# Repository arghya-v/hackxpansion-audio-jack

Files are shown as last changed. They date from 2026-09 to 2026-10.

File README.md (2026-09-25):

# Hackxpansion Audio Jack
This project adds stereo audio playback through a **TLV320DAC3100** DAC and a **3.5 mm headphone jack**, along with physical controls for playback.
<br/>
**Crates**: pkg:cargo/audio_jack_firmware@0.1.0
## Images
the case
pcb
3d

## Schematic
final schematic

### Audio Module

| GPIO  | Function |
| ----- | --- |
| GPIO0 | I²C SCL |
| GPIO1 | I²C SDA |
| GPIO2 | I²S BCLK |
| GPIO3 | I²S DIN |
| GPIO4 | I²S WCLK / LRCLK |
| GPIO5 | DAC MCLK |
| GPIO6 | DAC RESET |
| GPIO7 | Next |
| GPIO8 | Previous |
| GPIO9 | Play / Pause |

See the [Xpanse API docs](https://docs.rs/xpanse-api/latest/xpanse_api/index.html)

---

This was all possible thanks to [Hackspansion: A hackclub YSWS](http://hackxpansion.hackclub.com/)

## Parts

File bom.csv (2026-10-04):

Designator | Footprint | Quantity | Value | LCSC Part # | Price (USD)
C1, C4 | C469553_C1210 | 2 | 220µF | C469553 | 3.88
C2, C3, C5, C7 | C15850_C0805 | 4 | 10 µF | C15850 | 0.5208
CN1 | C2884926_AUDIO-TH_XKB_PJ-320A | 1 | PJ-320A | C2884926 | 0.4308
J1 | Male_Module | 1 | Included in kit
R1 | 0805 | 1 | 1k | Included in kit
R2 | 0805 | 1 | 62k | Included in kit
SW1, SW2, SW3 | SW_PUSH_6mm | 3 | Included in kit
U1 | C179677_LFCSP-32_L5_0-W5_0-P0_50-BL-EP | 1 | TLV320DAC3100IRHBR | C179677 | 3.7326
PCB |  |  | PCB |  | $4.00
PCBA Fee |  |  | PCBA Assembly |  | $20.7958
Shipping |  |  | Shipping |  | $6.45
TOTAL |  |  |  |  | $39.81

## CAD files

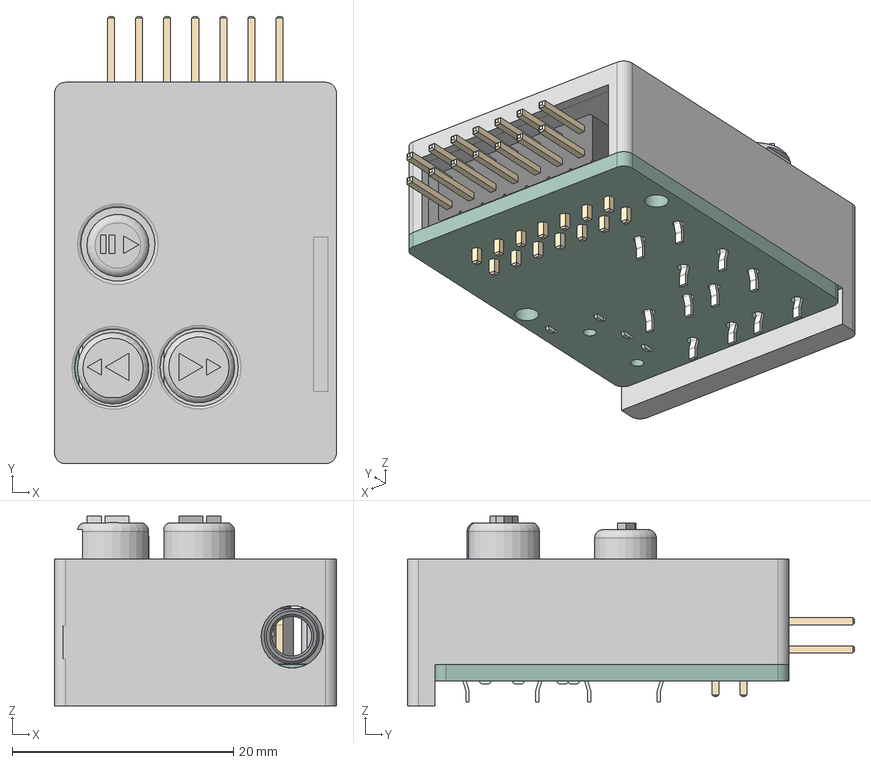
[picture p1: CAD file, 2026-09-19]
CAD/audio jack module.step
25.5 x 40.5 x 17.1 mm

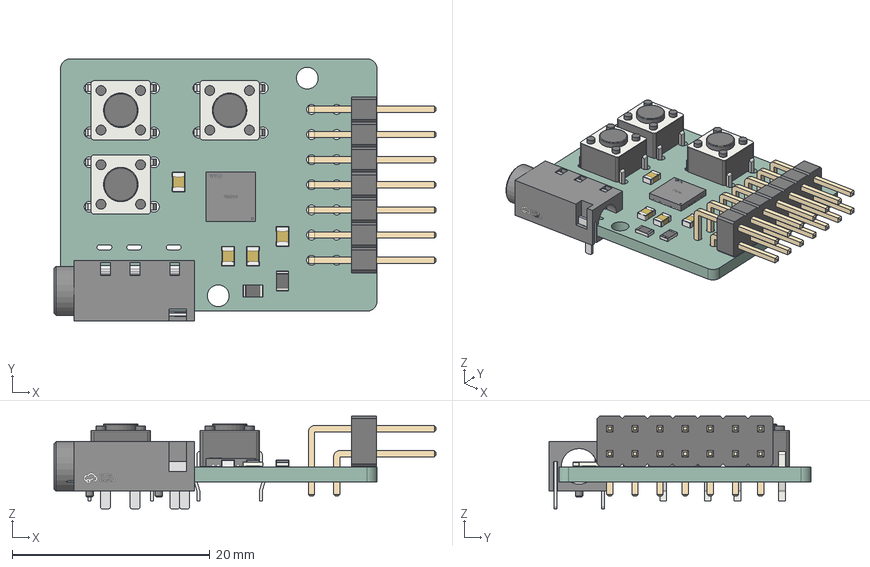
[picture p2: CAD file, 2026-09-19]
CAD/Audio Jack PCB.step
38.6 x 26.5 x 9.38 mm

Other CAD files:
CAD/Audio Jack.f3z

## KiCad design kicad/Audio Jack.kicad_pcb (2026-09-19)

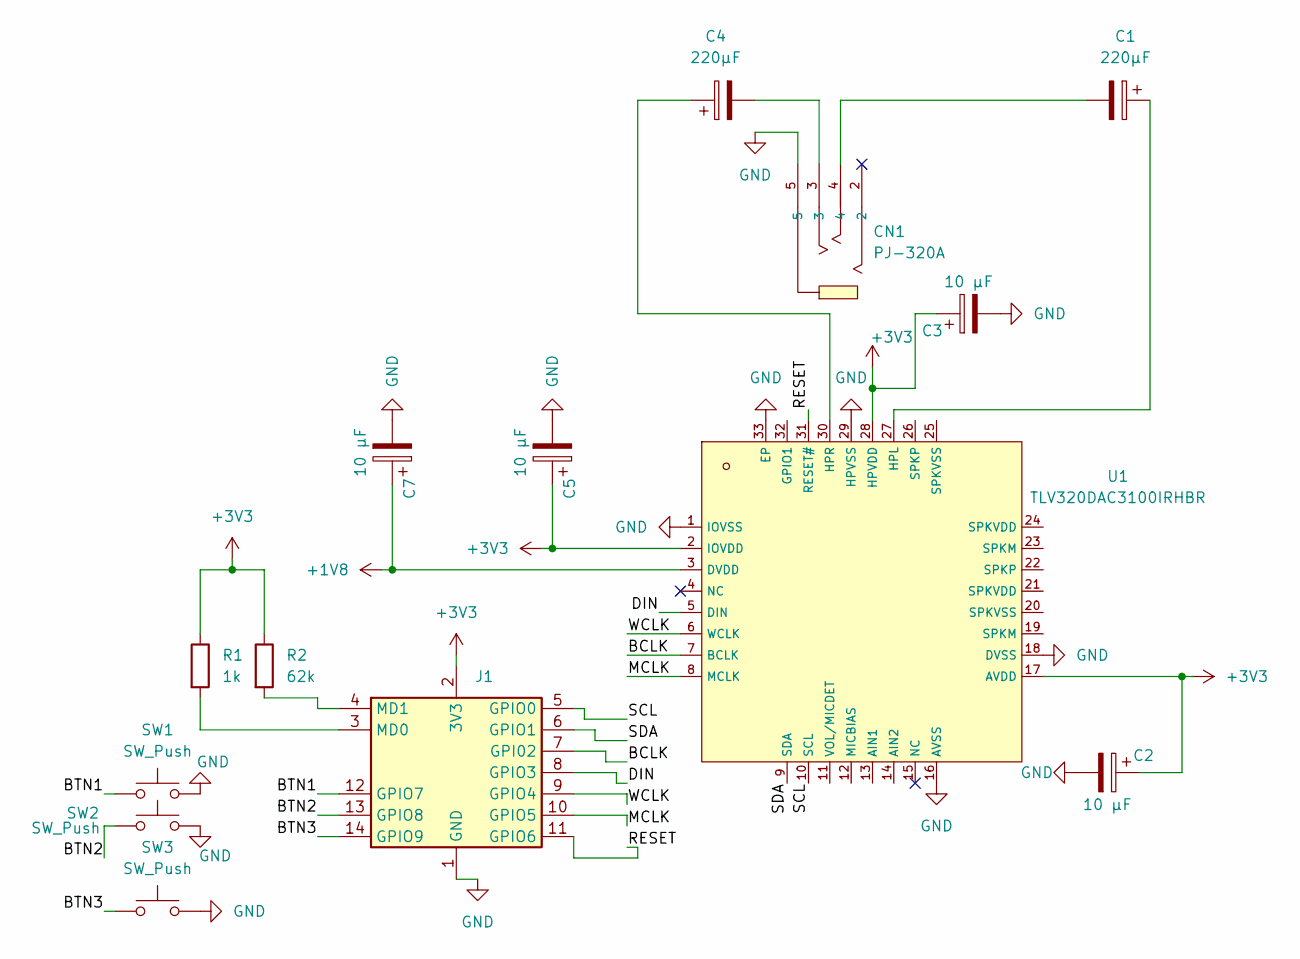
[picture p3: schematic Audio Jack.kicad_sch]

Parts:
C1, C4: 220µF; C469553_C1210
C2, C3, C5, C7: 10 µF; C15850_C0805
CN1: PJ-320A; C2884926_AUDIO-TH_XKB_PJ-320A; LCSC C2884926
J1: Male_Module
R1: 1k; R_0805_2012Metric_Pad1.20x1.40mm_HandSolder
R2: 62k; R_0805_2012Metric_Pad1.20x1.40mm_HandSolder
SW1, SW2, SW3: SW_Push; SW_PUSH_6mm
U1: TLV320DAC3100IRHBR; C179677_LFCSP-32_L5_0-W5_0-P0_50-BL-EP; LCSC C179677

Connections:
+1V8: C7.1, U1.3 (DVDD)
+3V3: C2.1, C3.1, C5.1, J1.2 (3V3), R1.1, R2.1, U1.2 (IOVDD), U1.17 (AVDD), U1.28 (HPVDD)
/BCLK: J1.7 (GPI02), U1.7 (BCLK)
/BTN1: J1.12 (GPIO7), SW1.1
/BTN2: J1.13 (GPIO8), SW2.1
/BTN3: J1.14 (GPIO9), SW3.1
/DIN: J1.8 (GPIO3), U1.5 (DIN)
/MCLK: J1.10 (GPIO5), U1.8 (MCLK)
/RESET: J1.11 (GPIO6), U1.31 (RESET#)
/SCL: J1.5 (GPIO0), U1.10 (SCL)
/SDA: J1.6 (GPIO1), U1.9 (SDA)
/WCLK: J1.9 (GPIO4), U1.6 (WCLK)
GND: C2.2, C3.2, C5.2, C7.2, CN1.5, J1.1 (GND), SW1.2, SW2.2, SW3.2, U1.1 (IOVSS), U1.16 (AVSS), U1.18 (DVSS), U1.29 (HPVSS), U1.33 (EP)
unnamed: C1.2, CN1.4
unnamed: C4.2, CN1.3
unnamed: J1.3 (MD0), R1.2
unnamed: J1.4 (MD1), R2.2
unnamed: C1.1, U1.27 (HPL)
unnamed: C4.1, U1.30 (HPR)

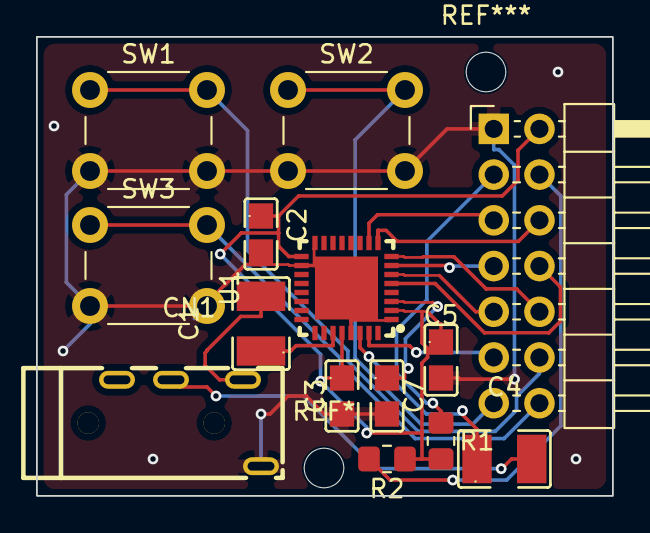
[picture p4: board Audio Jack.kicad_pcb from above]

Board: 2 copper layers, 32.0 x 25.5 mm, 14 parts (0 on the bottom side), 19 nets.

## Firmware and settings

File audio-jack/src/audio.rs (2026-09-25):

use embassy_rp::{
    dma,
    gpio::{Level, Output},
    interrupt::typelevel::{Binding, DMA_IRQ_0},
    peripherals::DMA_CH0,
    pio_programs::{
        clk::{PioClk, PioClkProgram},
        i2s::{PioI2sOut, PioI2sOutProgram},
    },
};

use embedded_hal_async::i2c::I2c;

use xpanse_api::{
    with_pio,
    bus::allocator::BusAllocator,
    driver::{Driver, DriverError, DriverMeta},
    gpio_bank::{BankPins, GpioBank},
    interfaces::buttons::{
        pin_button,
        A,
        B,
        X,
    },
    metadata::{ModuleDetectResistor, ModuleID, ModuleSlot},
    registry::Registry,
};

const DAC_ADDRESS: u8 = 0x18;

const SAMPLE_RATE: u32 = 48_000;
const BIT_DEPTH: u32 = 16;
const MCLK_FREQUENCY: u32 = 12_288_000;

#[derive(Copy, Clone)]
pub struct AudioDmaIrqs;

unsafe impl Binding<DMA_IRQ_0, dma::InterruptHandler<DMA_CH0>> for AudioDmaIrqs {}

pub struct AudioDriver;

impl DriverMeta for AudioDriver {
    const ID: ModuleID = ModuleID {
        md0: ModuleDetectResistor::R1K,
        md1: ModuleDetectResistor::R62K,
    };
}

impl<G> Driver<G> for AudioDriver
where
    G: BankPins,
{
    async fn create(
        bank: GpioBank<G>,
        slot: ModuleSlot,
        registry: &mut Registry,
        buses: &mut BusAllocator,
    ) -> Result<(), DriverError> {
        // RESET
        let mut reset = Output::new(
            bank.gpio6,
            Level::Low,
        );

        embassy_time::Timer::after_millis(5).await;

        reset.set_high();

        embassy_time::Timer::after_millis(10).await;

        core::mem::forget(reset);

        // I2C
        let mut i2c_bus = buses
            .create_i2c_bitbang(
                bank.gpio0,
                bank.gpio1,
                400_000,
            )
            .map_err(|_| DriverError::InitFailed)?;

        // DAC SOFTWARE RESET
        dac_write(
            &mut i2c_bus,
            0x00,
            0x01,
        )
        .await?;

        embassy_time::Timer::after_millis(10).await;

        // DAC CONFIGURATION
        configure_dac(&mut i2c_bus).await?;

        // BUTTONS
        registry.register(
            slot,
            Self::ID,
            pin_button::<A>(bank.gpio7.into()),
        );

        registry.register(
            slot,
            Self::ID,
            pin_button::<B>(bank.gpio8.into()),
        );

        registry.register(
            slot,
            Self::ID,
            pin_button::<X>(bank.gpio9.into()),
        );

        // DMA
        let dma = buses
            .request_dma::<DMA_CH0>()
            .map_err(|_| DriverError::InitFailed)?;

        // MCLK
        let mclk_pio = buses
            .request_pio(&[
                &bank.gpio5,
            ])
            .ok_or(DriverError::InitFailed)?;

        with_pio!(
            mclk_pio,
            mclk_common,
            mclk_sm,
            {
                let mclk_program = PioClkProgram::new(
                    &mut *mclk_common,
                );

                let mut mclk = PioClk::new(
                    &mut *mclk_common,
                    mclk_sm,
                    bank.gpio5,
                    &mclk_program,
                    MCLK_FREQUENCY,
                );

                mclk.start();

                core::mem::forget(mclk);
            }
        );

        // I2S
        let i2s_pio = buses
            .request_pio(&[
                &bank.gpio2,
                &bank.gpio3,
                &bank.gpio4,
            ])
            .ok_or(DriverError::InitFailed)?;

        with_pio!(
            i2s_pio,
            i2s_common,
            i2s_sm,
            {
                let i2s_program = PioI2sOutProgram::new(
                    &mut *i2s_common,
                );

                let mut i2s = PioI2sOut::new(
                    &mut *i2s_common,
                    i2s_sm,
                    dma,
                    AudioDmaIrqs,
                    bank.gpio3, // DIN
                    bank.gpio2, // BCLK
                    bank.gpio4, // LRCLK
                    SAMPLE_RATE,
                    BIT_DEPTH,
                    &i2s_program,
                );

                i2s.start();

                // Register I2S so applications can acquire it
                // and call i2s.write(samples).await.
                registry.register(
                    slot,
                    Self::ID,
                    i2s,
                );
            }
        );

        Ok(())
    }
}

async fn dac_write<I>(
    i2c: &mut I,
    register: u8,
    value: u8,
) -> Result<(), DriverError>
where
    I: I2c,
{
    i2c.write(
        DAC_ADDRESS,
        &[register, value],
    )
    .await
    .map_err(|_| DriverError::InitFailed)
}

async fn configure_dac<I>(
    i2c: &mut I,
) -> Result<(), DriverError>
where
    I: I2c,
{
    // CODEC_CLKIN = MCLK
    dac_write(i2c, 0x00, 0x00).await?;
    dac_write(i2c, 0x04, 0x00).await?;

    // NDAC = 8, powered
    dac_write(i2c, 0x0B, 0x88).await?;

    // MDAC = 2, powered
    dac_write(i2c, 0x0C, 0x82).await?;

    // DOSR = 128
    dac_write(i2c, 0x0D, 0x00).await?;
    dac_write(i2c, 0x0E, 0x80).await?;

    // I2S, 16-bit, codec slave
    dac_write(i2c, 0x1B, 0x00).await?;

    // Page 1
    dac_write(i2c, 0x00, 0x01).await?;

    // Common-mode voltage
    dac_write(i2c, 0x1F, 0x04).await?;

    // De-pop
    dac_write(i2c, 0x21, 0x4E).await?;

    // LDAC -> HPL
    // RDAC -> HPR
    dac_write(i2c, 0x23, 0x44).await?;

    // HPL unmuted
    dac_write(i2c, 0x28, 0x06).await?;

    // HPR unmuted
    dac_write(i2c, 0x29, 0x06).await?;

    // Power HPL + HPR
    dac_write(i2c, 0x1F, 0xC2).await?;

    // Analog output volume = -9 dB
    dac_write(i2c, 0x24, 0x92).await?;
    dac_write(i2c, 0x25, 0x92).await?;

    // Page 0
    dac_write(i2c, 0x00, 0x00).await?;

    // Power DAC L/R + soft stepping
    dac_write(i2c, 0x3F, 0xD4).await?;

    // Digital gain
    dac_write(i2c, 0x41, 0xD4).await?;
    dac_write(i2c, 0x42, 0xD4).await?;

    // Unmute DAC
    dac_write(i2c, 0x40, 0x00).await?;

    Ok(())
}

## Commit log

2026-09-03 done the driver
2026-09-04 Rename Audio Jack.step to Audio Jack.step
    [Audio Jack.step]
2026-09-19 Rename Audio Jack.kicad_pcb to kicad/Audio Jack.kicad_pcb
    [Audio Jack.kicad_pcb]
2026-09-19 Rename Audio Jack.kicad_prl to kicad/Audio Jack.kicad_prl
2026-09-19 Rename Audio Jack.kicad_pro to kicad/Audio Jack.kicad_pro
2026-09-19 Rename Audio Jack.kicad_sch to kicad/Audio Jack.kicad_sch
    [Audio Jack.kicad_sch]
2026-09-19 Fix image links in README.md
    Updated image links in the README for PCB and final schematic.
2026-09-19 Fix image links in README.md
    Updated image links for PCB and final schematic in README.
2026-10-04 Add price and total cost columns to bom.csv
    Added price information for components and total costs.
    [bom.csv]
2026-10-04 Change currency from CAD to USD in bom.csv
    [bom.csv]
2026-10-11 Modify BOM with new resistor values and total price
    Updated resistor values and prices in the BOM.
